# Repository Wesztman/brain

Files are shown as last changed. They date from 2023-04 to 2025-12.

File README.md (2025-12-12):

# Brain (based on [Urchin by Duckyb](https://github.com/duckyb/urchin))

Built

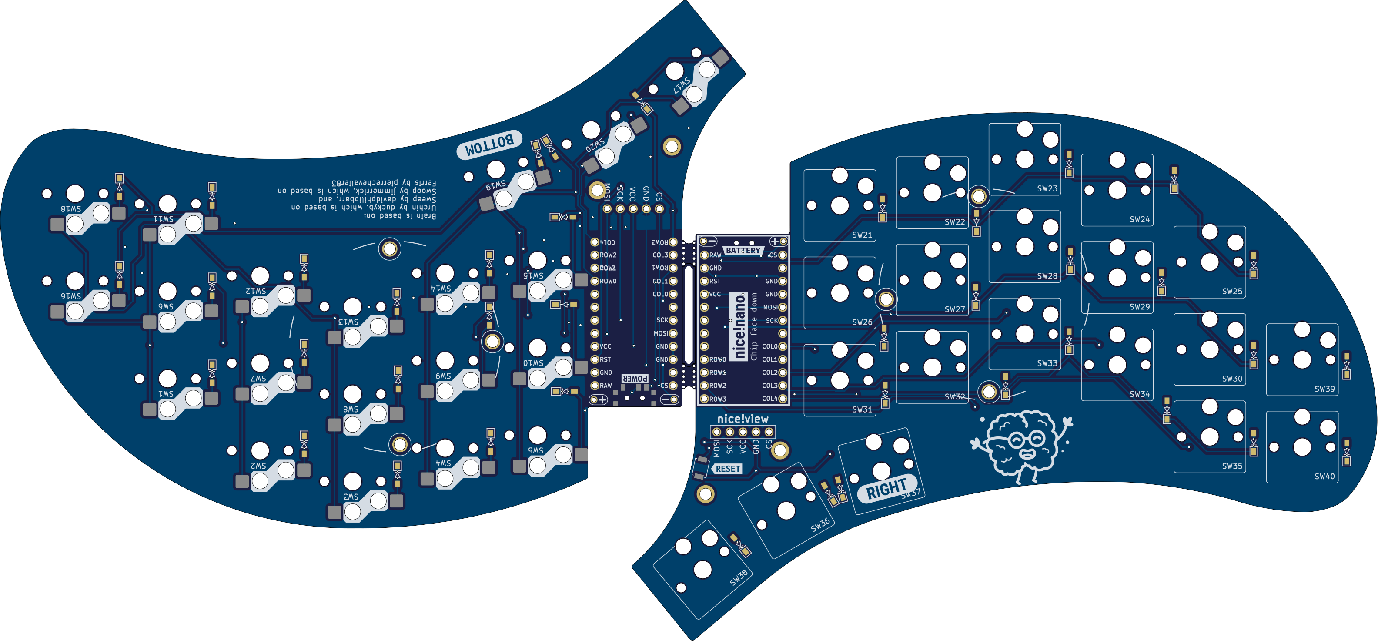
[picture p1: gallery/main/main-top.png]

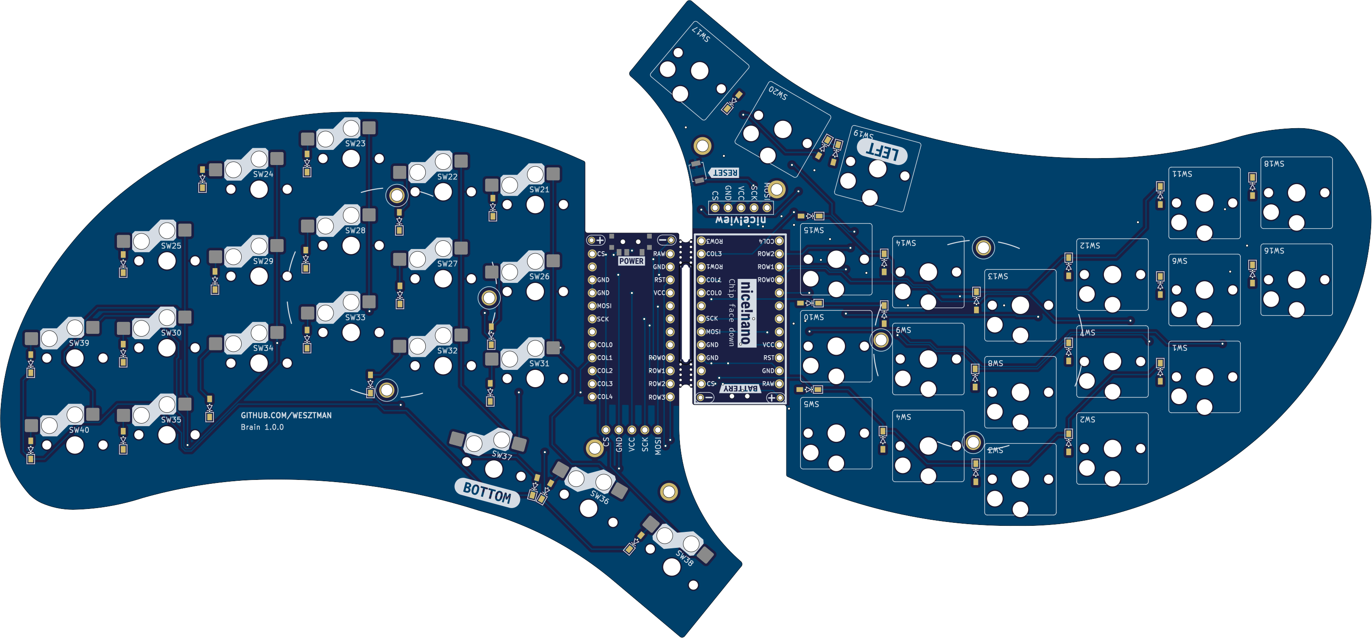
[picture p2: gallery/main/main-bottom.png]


<span>
  <a href="https://github.com/Wesztman/brain/commits/main">
    
  </a>
  <a href="https://github.com/Wesztman/brain/releases">
    
  </a>
  <a href="https://github.com/duckyb/urchin">
    
  </a>
  <a href="https://github.com/Wesztman/brain/blob/main/LICENSE">
    
  </a>
</span>

My first ever keyboard build was the Ferris Sweep, it's a wonderful keyboard! But I missed a few keys, the ctrl and shift keys on the left side and since I'm Swedish, I also wanted keys for åäö. Apart from this I was also only interested in wireless designs and was not interested in the TRRS jacks etc. The Urchin was the perfect solution for me, but I were still missing those oh so sought after keys. So I decided to make my own version of the Urchin, with a few extra keys and a little tweek to the edge cut to fit them nicely.

The result of this is the Brain, a wireless split keyboard based on the Urchin with 3 extra keys on each side. One extra pinky column with two keys and one extra thumb key. All 5 pinky keys are placed 2mm lower than the original Urchin keys, to make it easier to reach them.

**This is a strictly wireless-only design, and is only compatible with ZMK / nice!nano. Only Choc v1 switches + Hotswap are supported!**

## Features compared to [Urchin](https://github.com/duckyb/urchin)

- [x] Original pinky column lowered 2mm.
- [x] A new pinky column added with two buttons, also 2mm offset down from its neighbour.
- [x] One new thumb button added.
- [x] Holes that fit [Corne Acrylic cover](https://kriscables.com/product/corne-oled-cover-plate/) for nice!view.

## Feature requests for 2.0

- [ ] Raise last pinky column, maybe as much as 7-8 mm. For easier access to both the keys and not only the top one.
- [ ] Add back the fourth hole for tenting puck.
- [ ] Rotate the diode for switch 17, it's reversed now which causes confusion.
- [ ] Change the reset switch B3U-1000P(M) to regular tactile reset switch such as https://kriscables.com/product/tactile-reset-switch/ since it's a pain to get hold of the original reset switch.
- [ ] Do a non battery RGB blingbling version? I almost only use my keyboard without battery and a cable like this anyway https://www.amazon.se/dp/B0CYT426GZ?ref=ppx_yo2ov_dt_b_fed_asin_title&th=1

## Part list (for both sides)

#### Required

- 1× PCB Kit (files for it are in [releases](https://github.com/wesztman/brain/releases))
- 40× Kailh **CHOC** Hotswap Sockets (https://splitkb.com/products/kailh-hotswap-sockets?variant=39472161456205)
- 40× Kailh Choc v1 Switches (https://splitkb.com/collections/switches-and-keycaps/products/kailh-low-profile-choc-switches)
- 40× Keycaps 1u (https://splitkb.com/collections/switches-and-keycaps/products/blank-mbk-choc-low-profile-keycaps)
- 2× nice!nano (https://splitkb.com/products/nice-nano?_pos=1&_sid=0e4cc26b1&_ss=r)
- 40× SMD diodes (SOD-123) (https://kriscables.com/product/smd-diodes-sod123fl/)
- 48× mill-max machined pins (https://kriscables.com/product/mill-max-socket-pins/)
- 2× Pair of female mill-max headers (raised ones to fit battery) (https://kriscables.com/product/mill-max-low-profile-sockets/)
- 2× Lipo battery (301230) (https://kriscables.com/product/li-po-battery-3-7v-110mah/)
  - **OR** 1x split USB-C cable to use the keyboard without batteries (https://www.amazon.se/dp/B0CYT426GZ?ref=ppx_yo2ov_dt_b_fed_asin_title&th=1) (this also means you could go with "regular" millmax sockets and not the raised ones)
- 2x Power switch (MSK 12C02) (https://kriscables.com/product/msk-12c02-power-switch/)
  
#### Optional

- 2× nice!view (needs higher sockets to get level above raised mill-max sockets, TODO add exact ones) (https://splitkb.com/collections/keyboard-parts/products/nice-view)
- 2× Reset switch (B3U-1000P(M)) (https://www.digikey.se/sv/products/detail/omron-electronics-inc-emc-div/B3U-1000P/1534338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)
- 16× adhesive silicone feet 8mm (https://www.amazon.se/-/en/Adhesive-Silicone-Semicircle-Transparent-Furniture/dp/B09QSKVBL5)

## How do I make this?

Follow the the excellent build guide in the link below. The only difference is the 3 extra keys on each side.

Note that diodes should only be mounted on the "BOTTOM" side of the PCBs.

<a href="https://youtu.be/CHSh1-dJq24" target="_blank">

</a>

## Firmware

Brain supports ZMK only.

Firmware is provided by the lovely [iamDrakkir](https://github.com/iamDrakkir) and can be found in his [zmk-brain](https://github.com/iamDrakkir/zmk-brain) repo.

My personal fork can be found [here](https://github.com/Wesztman/zmk-config?organization=Wesztman&organization=Wesztman) if it's of interest for anyone (it has automatic picture generation of the layout for the readme #humbleflex)

## 3D Printed Cases

| Top | Side |
| --- | ---  |
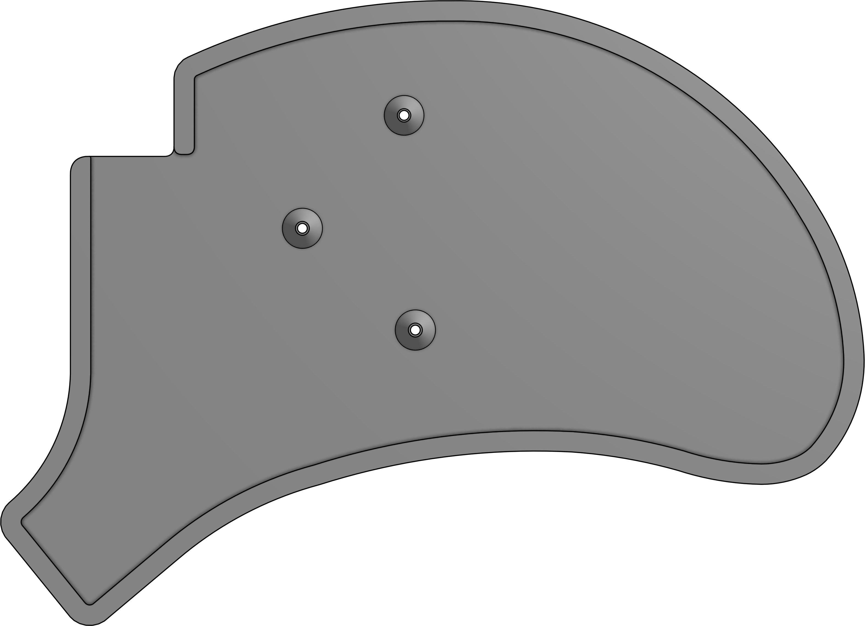
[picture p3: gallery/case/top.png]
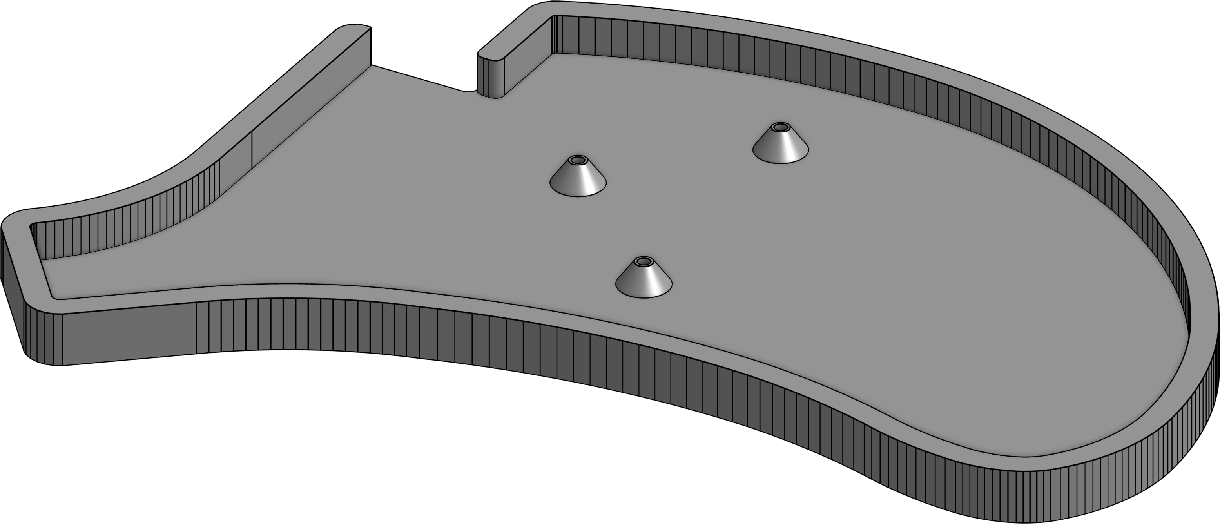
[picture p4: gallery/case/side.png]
|  |  |

| Closed | Open |
| --- | ---  |
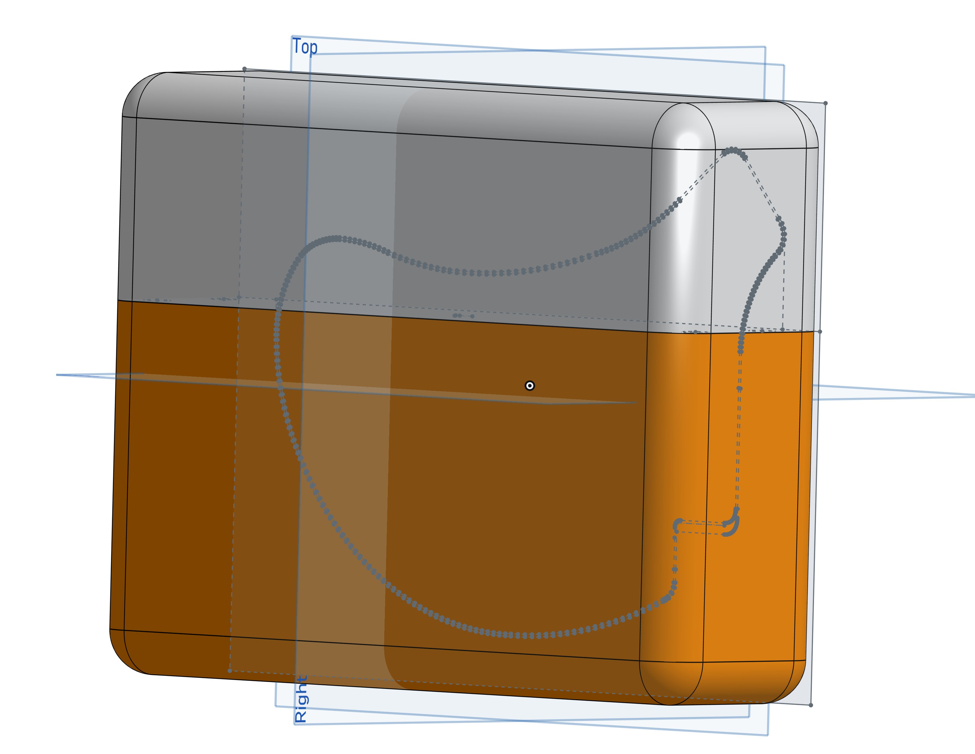
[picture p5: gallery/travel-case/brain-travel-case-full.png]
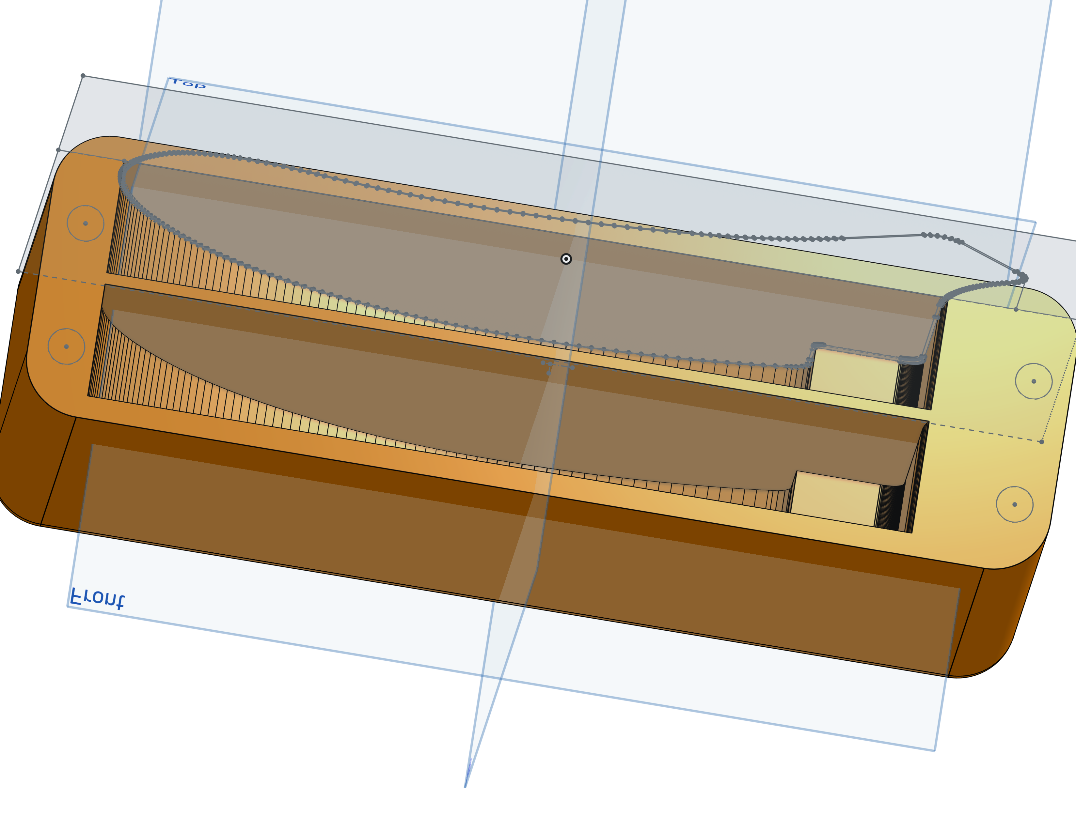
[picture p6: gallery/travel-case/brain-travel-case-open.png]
|  |  |

## Credits

- Urchin by [duckyb](https://github.com/duckyb/urchin)
- Logo by [Ariyanto Deni](https://thenounproject.com/ariyantodeni/)
- 3D case by [iamDrakkir](https://github.com/iamDrakkir)
- ZMK Firmware [iamDrakkir](https://github.com/iamDrakkir)

## Featured In

- [KBD Issue #122](https://kbd.news/Brain-2014.html)

## License
[MIT](https://github.com/Wesztman/brain/blob/main/LICENSE)

<a href="https://star-history.com/#Wesztman/brain&Date">
 <picture>
   <source media="(prefers-color-scheme: dark)" srcset="https://api.star-history.com/svg?repos=Wesztman/brain&type=Date&theme=dark" />
   <source media="(prefers-color-scheme: light)" srcset="https://api.star-history.com/svg?repos=Wesztman/brain&type=Date" />
   Star History Chart
 </picture>
</a>

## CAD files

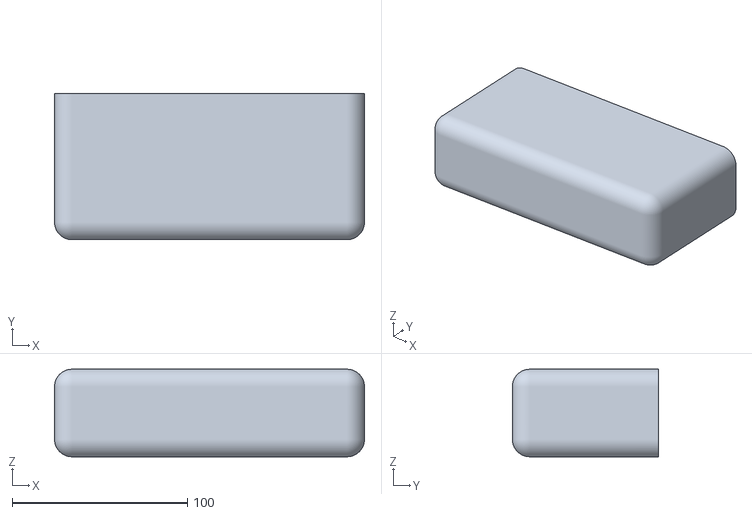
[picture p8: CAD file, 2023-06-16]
3d-prints/travel-case/brain-travel-case- main.stl
177.0 x 83.6 x 50.0

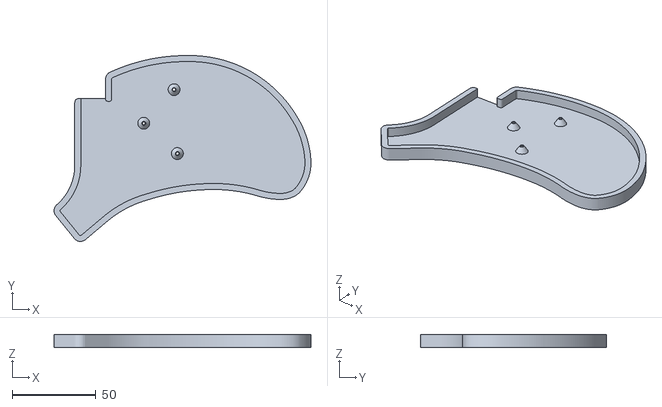
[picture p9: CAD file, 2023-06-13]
3d-prints/case/case-right.stl
153.0 x 110.7 x 7.50

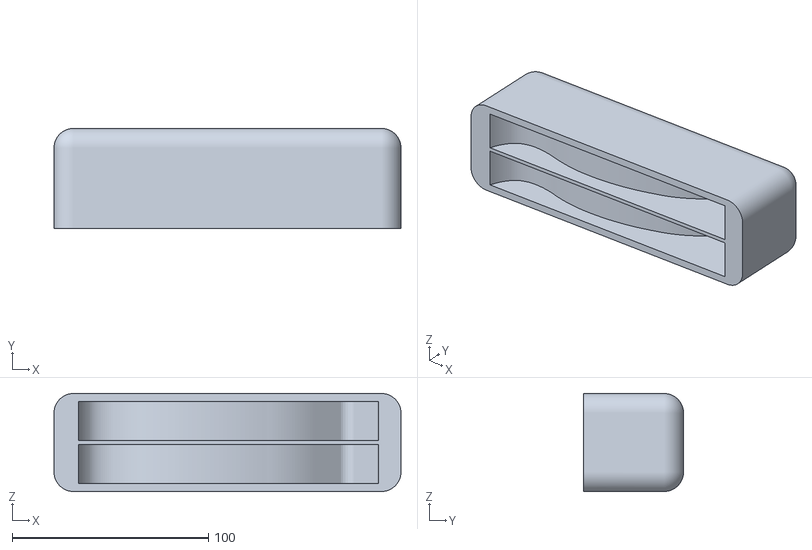
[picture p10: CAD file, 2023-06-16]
3d-prints/travel-case/brain-travel-case-lid.stl
177.0 x 51.1 x 50.0

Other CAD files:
3d-prints/case/case-left.stl

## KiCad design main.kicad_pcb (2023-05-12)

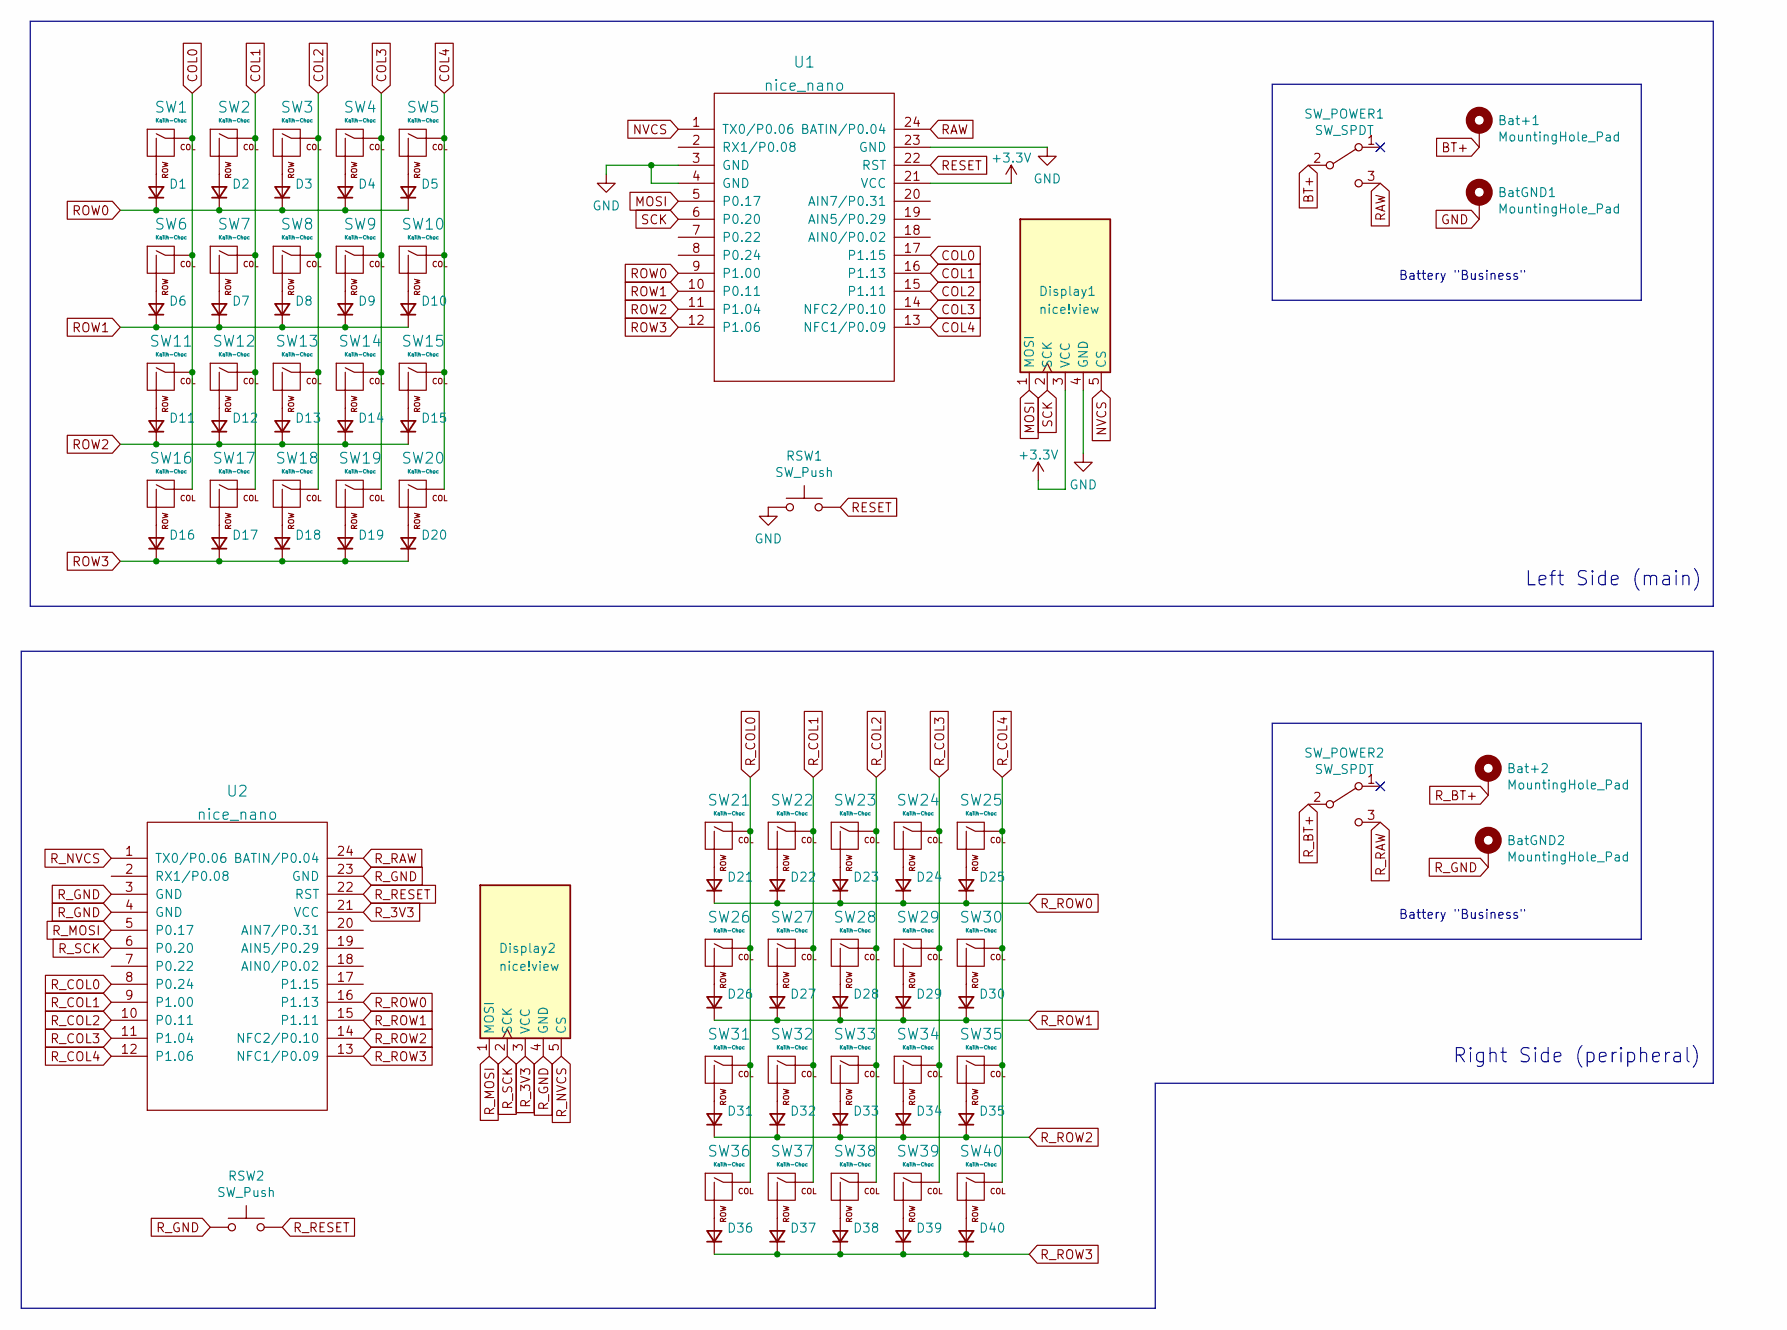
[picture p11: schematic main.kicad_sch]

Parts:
Bat+1, Bat+2: MountingHole_Pad; 1pin_Battery
BatGND1, BatGND2: MountingHole_Pad; 1pin_Battery
D1, D2, D3, D4, D5, D6, D7, D8, D9, D10, D11, D12, D13, D14, D15, D16, D17, D18, D19, D20, D21, D22, D23, D24, D25, D26, D27, D28, D29, D30, D31, D32, D33, D34, D35, D36, D37, D38, D39, D40: diode; SMD_Diode_Tiny
Display1, Display2: nice!view; nice_view
RSW1, RSW2: SW_Push; SW_RESET
SW1, SW2, SW3, SW4, SW5, SW6, SW7, SW8, SW9, SW10, SW11, SW12, SW13, SW14, SW15, SW16, SW17, SW18, SW19, SW20, SW21, SW22, SW23, SW24, SW25, SW26, SW27, SW28, SW29, SW30, SW31, SW32, SW33, SW34, SW35, SW36, SW37, SW38, SW39, SW40: Kailh-Choc; SW_Hotswap_Kailh_Choc_V1_tweaked
SW_POWER1, SW_POWER2: SW_SPDT; smt-slider-switch
U1, U2: nice_nano

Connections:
+3V3: Display1.3 (VCC), U1.21 (VCC)
BT+: Bat+1.1, SW_POWER1.2 (B)
COL0: SW1.1 (COL), SW6.1 (COL), SW11.1 (COL), SW16.1 (COL), U1.17 (P1.15)
COL1: SW2.1 (COL), SW7.1 (COL), SW12.1 (COL), SW17.1 (COL), U1.16 (P1.13)
COL2: SW3.1 (COL), SW8.1 (COL), SW13.1 (COL), SW18.1 (COL), U1.15 (P1.11)
COL3: SW4.1 (COL), SW9.1 (COL), SW14.1 (COL), SW19.1 (COL), U1.14 (NFC2/P0.10)
COL4: SW5.1 (COL), SW10.1 (COL), SW15.1 (COL), SW20.1 (COL), U1.13 (NFC1/P0.09)
GND: BatGND1.1, Display1.4 (GND), RSW1.1, U1.3 (GND), U1.4 (GND), U1.23 (GND)
MOSI: Display1.1 (MOSI), U1.5 (P0.17)
NVCS: Display1.5 (CS), U1.1 (TX0/P0.06)
unnamed: D1.2 (A), SW1.2 (ROW)
unnamed: D2.2 (A), SW2.2 (ROW)
unnamed: D3.2 (A), SW3.2 (ROW)
unnamed: D4.2 (A), SW4.2 (ROW)
unnamed: D5.2 (A), SW5.2 (ROW)
unnamed: D6.2 (A), SW6.2 (ROW)
unnamed: D7.2 (A), SW7.2 (ROW)
unnamed: D8.2 (A), SW8.2 (ROW)
unnamed: D9.2 (A), SW9.2 (ROW)
unnamed: D10.2 (A), SW10.2 (ROW)
unnamed: D11.2 (A), SW11.2 (ROW)
unnamed: D12.2 (A), SW12.2 (ROW)
unnamed: D13.2 (A), SW13.2 (ROW)
unnamed: D14.2 (A), SW14.2 (ROW)
unnamed: D15.2 (A), SW15.2 (ROW)
unnamed: D16.2 (A), SW16.2 (ROW)
unnamed: D17.2 (A), SW17.2 (ROW)
unnamed: D18.2 (A), SW18.2 (ROW)
unnamed: D19.2 (A), SW19.2 (ROW)
unnamed: D20.2 (A), SW20.2 (ROW)
unnamed: D21.2 (A), SW21.2 (ROW)
unnamed: D22.2 (A), SW22.2 (ROW)
unnamed: D23.2 (A), SW23.2 (ROW)
unnamed: D24.2 (A), SW24.2 (ROW)
unnamed: D25.2 (A), SW25.2 (ROW)
unnamed: D26.2 (A), SW26.2 (ROW)
unnamed: D27.2 (A), SW27.2 (ROW)
unnamed: D28.2 (A), SW28.2 (ROW)
unnamed: D29.2 (A), SW29.2 (ROW)
unnamed: D30.2 (A), SW30.2 (ROW)
unnamed: D31.2 (A), SW31.2 (ROW)
unnamed: D32.2 (A), SW32.2 (ROW)
unnamed: D33.2 (A), SW33.2 (ROW)
unnamed: D34.2 (A), SW34.2 (ROW)
unnamed: D35.2 (A), SW35.2 (ROW)
unnamed: D36.2 (A), SW36.2 (ROW)
unnamed: D37.2 (A), SW37.2 (ROW)
unnamed: D38.2 (A), SW38.2 (ROW)
unnamed: D39.2 (A), SW39.2 (ROW)
unnamed: D40.2 (A), SW40.2 (ROW)
RAW: SW_POWER1.3 (C), U1.24 (BATIN/P0.04)
RESET: RSW1.2, U1.22 (RST)
ROW0: D1.1 (K), D2.1 (K), D3.1 (K), D4.1 (K), D5.1 (K), U1.9 (P1.00)
ROW1: D6.1 (K), D7.1 (K), D8.1 (K), D9.1 (K), D10.1 (K), U1.10 (P0.11)
ROW2: D11.1 (K), D12.1 (K), D13.1 (K), D14.1 (K), D15.1 (K), U1.11 (P1.04)
ROW3: D16.1 (K), D17.1 (K), D18.1 (K), D19.1 (K), D20.1 (K), U1.12 (P1.06)
R_3V3: Display2.3 (VCC), U2.21 (VCC)
R_BT+: Bat+2.1, SW_POWER2.2 (B)
R_COL0: SW21.1 (COL), SW26.1 (COL), SW31.1 (COL), SW36.1 (COL), U2.8 (P0.24)
R_COL1: SW22.1 (COL), SW27.1 (COL), SW32.1 (COL), SW37.1 (COL), U2.9 (P1.00)
R_COL2: SW23.1 (COL), SW28.1 (COL), SW33.1 (COL), SW38.1 (COL), U2.10 (P0.11)
R_COL3: SW24.1 (COL), SW29.1 (COL), SW34.1 (COL), SW39.1 (COL), U2.11 (P1.04)
R_COL4: SW25.1 (COL), SW30.1 (COL), SW35.1 (COL), SW40.1 (COL), U2.12 (P1.06)
R_GND: BatGND2.1, Display2.4 (GND), RSW2.1, U2.3 (GND), U2.4 (GND), U2.23 (GND)
R_MOSI: Display2.1 (MOSI), U2.5 (P0.17)
R_NVCS: Display2.5 (CS), U2.1 (TX0/P0.06)
R_RAW: SW_POWER2.3 (C), U2.24 (BATIN/P0.04)
R_RESET: RSW2.2, U2.22 (RST)
R_ROW0: D21.1 (K), D22.1 (K), D23.1 (K), D24.1 (K), D25.1 (K), U2.16 (P1.13)
R_ROW1: D26.1 (K), D27.1 (K), D28.1 (K), D29.1 (K), D30.1 (K), U2.15 (P1.11)
R_ROW2: D31.1 (K), D32.1 (K), D33.1 (K), D34.1 (K), D35.1 (K), U2.14 (NFC2/P0.10)
R_ROW3: D36.1 (K), D37.1 (K), D38.1 (K), D39.1 (K), D40.1 (K), U2.13 (NFC1/P0.09)
R_SCK: Display2.2 (SCK), U2.6 (P0.20)
SCK: Display1.2 (SCK), U1.6 (P0.20)

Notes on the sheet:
Right Side (peripheral)
Battery "Business"
Left Side (main)

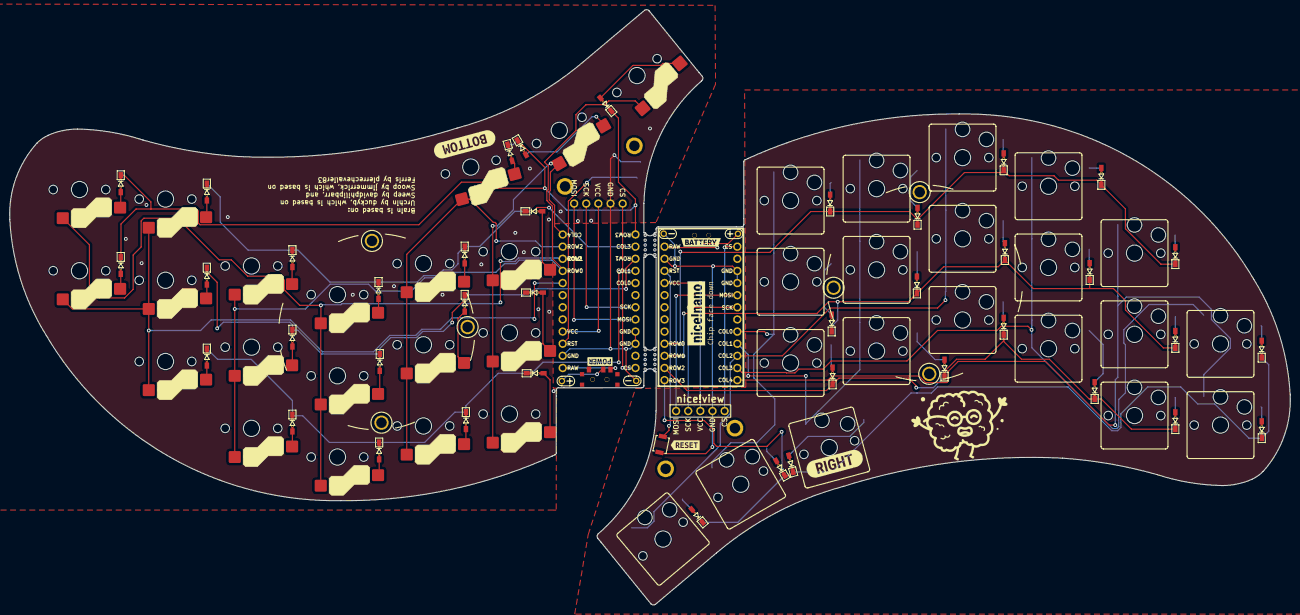
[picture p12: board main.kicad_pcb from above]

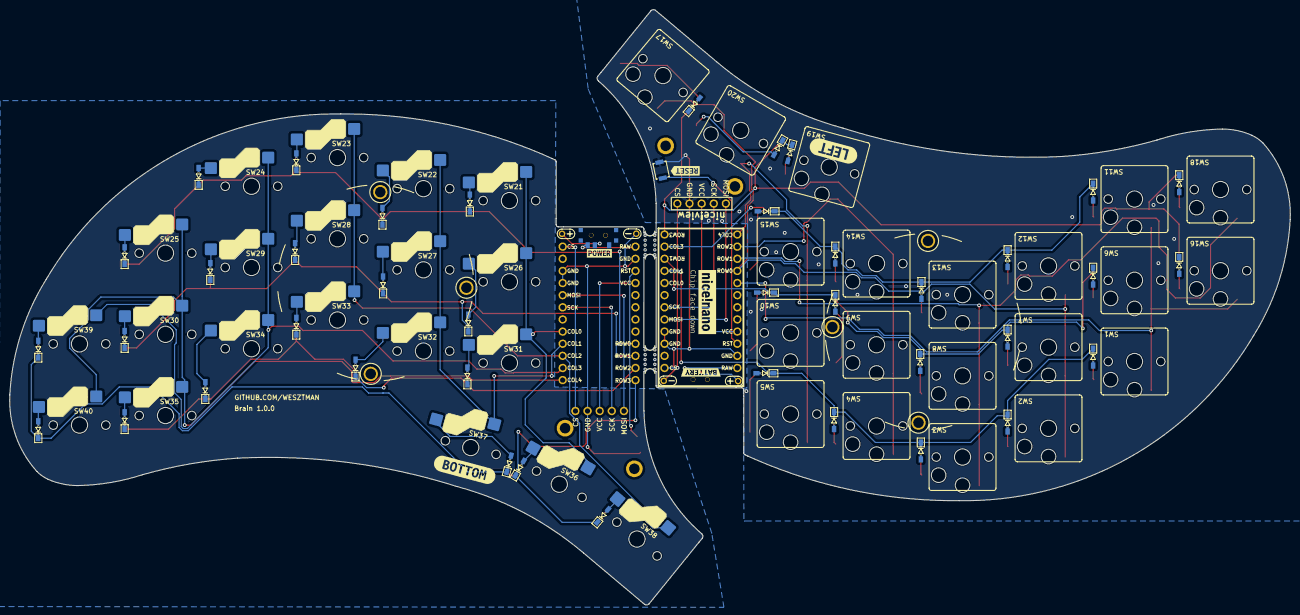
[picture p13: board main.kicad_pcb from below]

Board: 2 copper layers, 268.1 x 124.6 mm, 110 parts (56 on the bottom side), 74 nets.

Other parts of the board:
REF_PUCK_R: Tenting Puck; Tenting_Puck2_no_pads
REF_PUCK_R#2: Tenting Puck; Tenting_Puck2_no_pads
kibuzzard-636588C8, kibuzzard-636588C8#2: G***; kibuzzard-636588C8
kibuzzard-636592CC: G***; kibuzzard-636592CC
kibuzzard-6361375E, kibuzzard-6361375E#2: G***; kibuzzard-6361375E
kibuzzard-6365884B: G***; kibuzzard-6365884B
kibuzzard-6365950B: G***; kibuzzard-6365950B
kibuzzard-6365951E: G***; kibuzzard-6365951E
kibuzzard-63658823: G***; kibuzzard-63658823
kibuzzard-63658830: G***; kibuzzard-63658830
kibuzzard-63658865: G***; kibuzzard-63658865
kibuzzard-63659296: G***; kibuzzard-63659296
kibuzzard-63659465: G***; kibuzzard-63659465
kibuzzard-63659477: G***; kibuzzard-63659477
mouse-bite-2mm-slot, mouse-bite-2mm-slot#2: VAL**; mouse-bite-5mm-slot-with-space-for-track

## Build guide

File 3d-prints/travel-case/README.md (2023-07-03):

# 3D printed travel case for the Brain

The travel case is designed in two parts and are connected with print in place magnets. The inside is designed to fit the Brain with the [3d printed case](../case/README.md). The lid snaps into place in an utterly satisfying way.

## Preview

| Closed | Open |
| --- | ---  |
|  |  |

## Design

The design is split into two parts and are connected with print-in-place magnets. Meaning that the print is paused at a certain height and the magnets are inserted into the print. The print is then resumed and the magnets are encased in the print. The magnets used are 6x3mm neodymium magnets.

[Onshape design](https://cad.onshape.com/documents/a8c7393d87d948afba2c6e43/w/ea731c1d3c5cb85e11790472/e/4dde8ed377b236e8ab6f5f7d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)

## Printing

Printed in PLA with 0.2mm layer height and 20% infill. No supports are needed.

At layer 18 (3.6mm) the print is paused and the magnets are inserted into the print. The print is then resumed and the magnets are encased in the print.

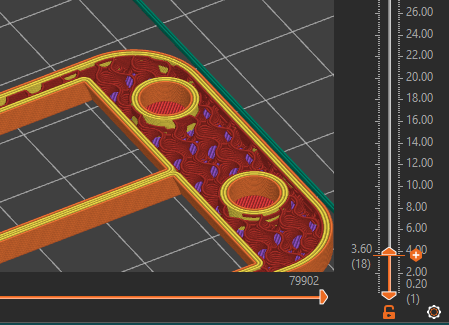
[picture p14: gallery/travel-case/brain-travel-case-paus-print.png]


Print placement.

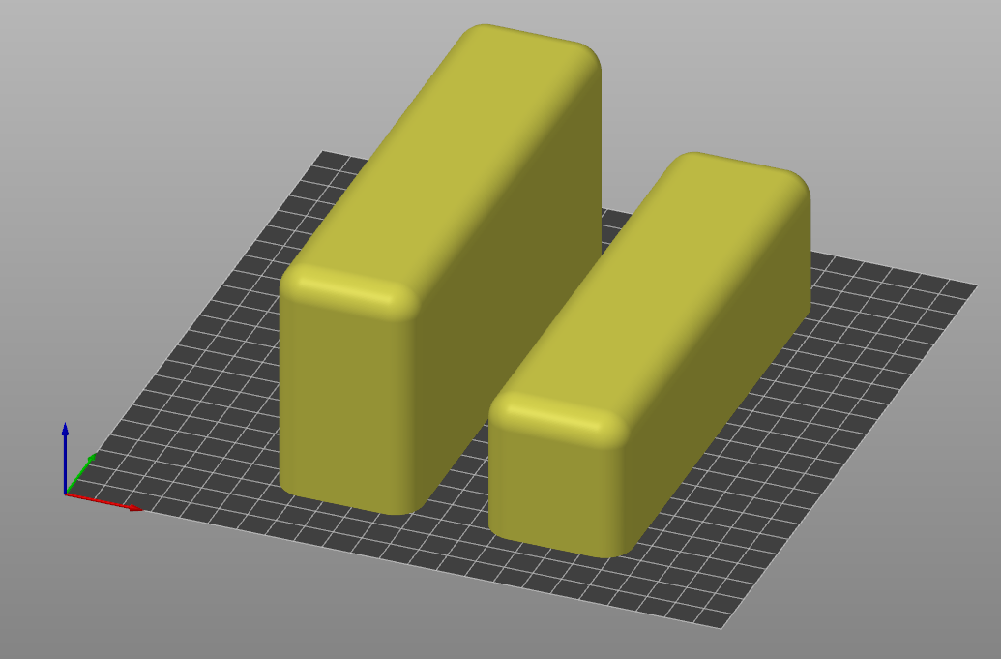
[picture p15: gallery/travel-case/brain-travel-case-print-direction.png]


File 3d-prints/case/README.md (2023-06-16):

# 3D printed case for the Brain

The case is specifically designed to be used with a foam layer (~2mm) between the PCB and the case for additional cushioning and to reduce the noise of the switches. Additionally, the case includes 8x rubber feet holes (8mm in diameter) to provide additional stability and prevent the case from sliding around during use.

## Preview

| Top | Side |
| --- | ---  |
|  |  |

## Design

The design is split into two parts, one for each half of the split keyboard. The case has screw holes that match M2 screws (~5mm), which can be used to fasten the case together.

[Onshape design](https://cad.onshape.com/documents/ca702f1514417f775ac77674/w/a5f5f447b02d600e7c1a381b/e/59998fea22245e9ac184edc3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)

## Printing

Printed in PLA with 0.2mm layer height and 100% infill. No supports are needed.

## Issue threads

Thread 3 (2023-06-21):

Is the diode direction for SW17 labeled incorrectly?

twalker, 2023-06-21:
Thank you for such a great 40% design--the extra thumb key and organic shape are delightful.

The diode direction on the PCB for switch 17 (left half) is reversed from the surrounding key switches, and from switch 38 (right half).
Is this by design, or a mislabeled diode direction?

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

_I do not know if it's related, but I've mounted the diode on switch 38 in both polarities, but that half does not send any key codes._

twalker, 2023-06-25:
@Wesztman
Would you mind answering this question when it's convenient? Thank you.

Wesztman, 2023-06-25:
Hi @twalker!

Sorry for not responding, I had managed to turn of all notifications except @ 😉 so good call there!

Thanks for noticing, I checked my own keyboard and in KiCad and I seem to have rotated this at some point, probably just to get a shorter path for the traces. Not thinking about that it might be confusing in the future 😅

But you should mount all diodes according to the labels 😊 so the one on switch 17 should be switched.

Then there should be no issues, that is how it looks on my own keyboard 😊

It's worth noting that diodes should only be mounted on the "BOTTOM" side of the PCB:s, I might add that to the readme actually.

I should go ahead and add to my todo list to rotate the 17 diode in the next release 😊

twalker, 2023-06-25:
Thank you for clearing up my confusion. Both reversing switch 17s diode direction, and noting that all diodes should be on the bottom of the PCB will help prevent confusion. All the other labeling on the board is quite clear.

I've done a fair bit of troubleshooting on the right half of my build and cannot get it to send keycodes. I'll rebuild the right half with more confidence on the diode orientation. Thanks again.

twalker, 2023-06-25:
@Wesztman ,

FYI: I built a new right half following the diode labeling, and have successfully paired it with the left half. I'm pretty sure the issue with my build was not hardware-based, but not being able to pair the halves w/ZMK. However, the nice!view on the right half is still not displaying any information.

Should the nice!view display something on both displays when both halves have a display?

iamDrakkir, 2023-06-26:
The nice!view should work on both halves :)

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

twalker, 2023-06-27:
Thank you @iamDrakkir, that helps me rule out the firmware and narrow down my issue to the microcontroller.

What a classy looking build. I can't wait to get a case printed and be using a brain as a daily driver. 😸

twalker, 2023-07-09:
FWIW, the root cause was the firmware. After flashing the [erase reset firmware](https://github.com/joric/nrfmicro/wiki/Bootloader#nrf52840), the nice!view displayed properly and the halves paired.
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

Closed 2023-06-25.

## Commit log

2023-03-26 Sharp pinky corner
    [main.kicad_pcb]
2023-03-27 Left outline complete
    [main.kicad_pcb]
2023-03-27 Components and edge cut for right pcb
    [main.kicad_pcb]
2023-03-28 Update run-kibot.yml
    This change sets the kibot workflow to use kicad v7 to match your local version. This allows the automated workflow to update the PCB preview in the main readme file when you change the pcb.
2023-03-28 Fixed outline for right hand
    [main.kicad_pcb]
2023-03-28 Finished, time for cleanup
    [main.kicad_pcb]
2023-03-28 Flipped right board
    [main.kicad_pcb]
2023-03-28 Flipped right side and added mouse bites
    [main.kicad_pcb]
2023-03-28 Moved right front to right side
    [main.kicad_pcb]
2023-03-28 Added brain icon
    [main.kicad_pcb]
2023-03-28 Changed icon to copper
    [main.kicad_pcb]
2023-03-30 Added pads for niceview cover
    [main.kicad_pcb]
2023-03-30 Rotated back card
    [main.kicad_pcb]
2023-03-30 Added missing parts to schematic.
    [main.kicad_sch]
2023-03-30 Updated schematic and updated pcb
    [main.kicad_pcb, main.kicad_sch]
2023-03-30 Re-annotated all labels
    [main.kicad_pcb, main.kicad_sch]
2023-03-31 Moved edge cut to encircle pad which was cut of before
    [main.kicad_pcb]
2023-03-31 Added vias and copper fill
    [main.kicad_pcb]
2023-03-31 Version 0.1.0
    [main.kicad_pcb]
2023-04-01 Changed icon to silkscreen
    [main.kicad_pcb]
2023-04-02 remove cases for urchin
    [Urchin_Tray_Case.f3d, case-left.step, case-left.stl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]
2023-04-02 Add case and preview picture
    [Case Left.stl, Case_Right.stl, case-left.step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]
2023-04-02 Add Readme for case
2023-04-03 Fixed issue with hole cutting trace. updated version
    [main.kicad_pcb]
2023-04-03 Removed alot of small unconnected traces
    [main.kicad_pcb]
2023-05-09 Update left case
    [Case Left.stl, Case_Left.stl]
2023-05-12 Updated version text to 1.0.0
    [main.kicad_pcb]
2023-05-30 update case
    Add 1.5mm above the usb-output to protect the power-switch
    [Case_Left.step, Case_Right.step]
2023-05-30 .stl files
    [Case_Left.stl, Case_Right.stl]
2023-05-30 Remove .step files
    [Case_Left.step, Case_Right.step]
2023-06-13 1mm extra at the usb cutout
    [Case_Left.stl, Case_Right.stl]
2023-06-16 Moved case to new folder
    [case-left.stl, case-right.stl]
2023-06-16 Added travel case
    [brain-travel-case- main.stl, brain-travel-case-lid.stl]
